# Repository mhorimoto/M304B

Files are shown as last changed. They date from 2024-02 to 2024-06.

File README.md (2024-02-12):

# M304B
UECS Controller Shield for Arduino MEGA I/F
Baby size

外観上の特徴としては、基板サイズが約半分となる。

## 1. PARTS

### 1-1. NIC

DIPタイプのW5500チップを使用したNICを使用する．

Tzt smart electronics USR-ES
https://ja.aliexpress.com/item/4000226162371.html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

### 1-2. LCD

20x4 Parallel connection (秋月コード P-10844)

## 2. Pin Assign

### 2-1. LCD (J1)

| I/O PIN | NAME | LCD PIN |
|:---:|---|:---:|
| | GND  | 1 |
| | Vdd  | 2 |
| | Vo | 3 |
| 37 | RS | 4 |
| 38 | R/W  | 5 |
| 39 | ENA  | 6 |
| 40 | DB0  | 7 |
| 41 | DB1  | 8 |
| 42 | DB2  | 9 |
| 43 | DB3  | 10 |
| 44 | DB4  | 11 |
| 45 | DB5  | 12 |
| 46 | DB6  | 13 |
| 47 | DB7  | 14 |
| | BL+  | 15 |
| | BL-  | 16 |

データピン８ピンすべて接続してある．

### 2-2. Relay OUT (J2)
リレー制御用のポートである．アクティブロー(負論理)である．

| J2 PIN | NAME |I/O PIN |
|:---:|---|:---:|
| 1 | RLY1 | 22 |
| 2 | RLY2 | 23 |
| 3 | RLY3 | 24 |
| 4 | RLY4 | 25 |
| 5 | RLY5 | 26 |
| 6 | RLY6 | 27 |
| 7 | RLY7 | 28 |
| 8 | RLY8 | 29 |
| 9 | Vdd  | +5V  |

リレー制御の自動・手動状態検知のための端子(STAT)はI/O PIN=31である.

|状態|D31の状態|
|:--:|:---:|
|自動| H |
|手動| L |

### 2-3. iM920 Interface (J3)
=== 排除する ===
iM920用のインタフェースで3.3V駆動です.

| J3 PIN | NAME  | I/O PIN |
|:---:|---|:---:|
| 1 | RESET | D6 |
| 2 | BUSY  | D2 |
| 3 | GND | GND |
| 4 | Vcc | 3.3V  |
| 5 | TX | D19(Rx) |
| 6 | RX | D18(Tx) |
| 7 | STATUS| D5 |

### 2-4. GNSS(GPS) Interface (J4)
=== 排除する ===
秋月電子通商のGNSSキット用．

| J4 PIN | NAME  | I/O PIN  |
|:---:|---|:---:|
| 1 | 1PPS  | D4 |
| 2 | RX | D14(Tx3) |
| 3 | TX | D15(Rx3) |
| 4 | GND | GND |
| 5 | Vcc | +5V |

### 2-5. Arrow Switch

アクティブローである．

| I/O PIN | 表示|回路図記号|
|:---:|:---:|:----:|
| 32 | 決定 (SW_ENTER)| SW6 |
| 33 |  ↑ (SW_A) | SW2 |
| 34 |  ↓ (SW_B) | SW3 |
| 35 |  ← (SW_C) | SW4 |
| 36 |  → (SW_D) | SW5 |

### 2-6. 選択
=== ADCを排除し ===
=== ロータリーエンコーダを使う。===
ADCに接続している．ロータリーエンコーダの代わりにADCの出力を得て選択する．

| I/O PIN | 表示 | 回路図記号 |
|:----:|:---:|:---:|
|  A15 | 選択(SELECTOR) | RV2 |

### 2-7. RESET
リセットボタンはArduino MEGAのRESETピンへ直結していると同時にNICのRESETピンにも接続されている．アクティブローである．

### 2-8. SAFEMODE Switch
UECSの初期設定を行う際に必要となるスイッチ．UARDECS_Libraryの既定値である

| I/O PIN | 表示 | 回路図記号 |
|:----:|:---:|:---:|
|  D3  | 初期設定(SAFEMODE) | SW7 |

### 2-9. JA pins (Analog ports)
以下のピン配置で3.3V用8ポート，5V用7ポートがある．
ソフトウェアで入出力の両用に使える．

| XH PIN | 意味 |
|:---:|:---|
| 1 | GND |
| 2 | CPUのAnalog port  |
| 3 | 電源 (3.3V or 5V)  |

コネクタとADCポートの関係

JA2〜JA7削除
JA10〜JA14削除

| PORT名 | 電圧 | I/O PIN |
|:-----:|:----:|:---:|
|  JA0  | 3.3V | A0 |
|  JA1  | 3.3V | A1 |
|  JA2  | 3.3V | A2 |
|  JA3  | 3.3V | A3 |
|  JA4  | 3.3V | A4 |
|  JA5  | 3.3V | A5 |
|  JA6  | 3.3V | A6 |
|  JA7  | 3.3V | A7 |
|  JA8  |  5V  | A8 |
|  JA9  |  5V  | A9 |
|  JA10 |  5V  | A10 |
|  JA11 |  5V  | A11 |
|  JA12 |  5V  | A12 |
|  JA13 |  5V  | A13 |
|  JA14 |  5V  | A14 |

### 2-10. JD pins (Digital ports)
以下のピン配置で7ポートある．ソフトウェアで入出力を切り替えられる．

| XH PIN | 意味 |
|:---:|:---|
| 1 | GND |
| 2 | CPUのDigital port  |

コネクタとDIOポートの関係
JD10〜JD13削除

| PORT名 | I/O PIN |
|:-----:|:---:|
|  JD7  | D7 |
|  JD8  | D8 |
|  JD9  | D9 |
|  JD10 | D10 |
|  JD11 | D11 |
|  JD12 | D12 |
|  JD13 | D13 |

### 2-11. UART (JX2)
外部の装置とUART接続するためのポートが準備されている．
ポート名はJX2．電圧レベルは5V．接続先の送受関係は，2ピンに対象体のRxを3ピンにTxを接続する．

| XH PIN番号 | I/O PIN |
|:---:|:---:|
| 1 | GND |
| 2 | D16 (Tx2) |
| 3 | D17 (Rx2) |

### 2-12. TEST Pad
独自にテストを行う際の独立したDIO pinのパッド．

| Pad名 | I/O PIN |
|:-----:|:---:|
| JD30  | D30 |
| JD48  | D48 |
| JD49  | D49 |

### 2-13. I2C Devices

標準で搭載されているI2Cデバイスは以下の通り．

| Address | 名称 |
|:---:|:---|
| 0x50 | EEPROM AT24C256 |
| 0x68 | RTC DS1307 |

* EEPROM
AT24C256 を使用している．32kBytesの容量がある．
* RTC (Address=0x68)
DS1307を使用してる．(DS1307RTC)

https://stackedit.io/app#

## 3.Software

### 3-1. AT24C256 EEPROM

データの保存を行う他に重要な役割がある．

UECS-IDとMACアドレスを以下のアドレスに記録する．MSB first，Big endianにて記録する．

|  Address | Data |
|:---:|:---|
| 00H〜05H | UECS-ID |
| 06H〜0BH | MAC Address |
| 0CH〜1FH | Reserved |
| 20H〜7FFFH | Data |

* UECS-ID: 10100C00000B
* MAC Address: 02:A2:73:0B:xx:xx

### 3-2. M304_Library

M304_Libraryは，M304を使用する際に初期化やポート名を決定してくれるヘッダファイルと若干の関数がまとめられたファイル．
現状では，Arduino-IDE(arduino-cli)が使用できるディレクトリにコピーして使う．
将来的には，このディレクトリから分離されて，Arduino-IDEなどのライブラリ管理から管理できるようにする．
同時にUARDECS_MEGAとの整合も図る．

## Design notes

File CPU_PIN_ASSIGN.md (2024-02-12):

# M304 Arduino CPU Pin Assign

## 1. Pin Assign 

| I/O PIN | NAME | LCD PIN |
|:---:|---|:---:|
| | GND  | 1 |
| | Vdd  | 2 |
| | Vo | 3 |
| 37 | RS | 4 |
| 38 | R/W  | 5 |
| 39 | ENA  | 6 |
| 40 | DB0  | 7 |
| 41 | DB1  | 8 |
| 42 | DB2  | 9 |
| 43 | DB3  | 10 |
| 44 | DB4  | 11 |
| 45 | DB5  | 12 |
| 46 | DB6  | 13 |
| 47 | DB7  | 14 |
| | BL+  | 15 |
| | BL-  | 16 |

データピン８ピンすべて接続してある．

### 2-2. Relay OUT (J2)
リレー制御用のポートである．アクティブロー(負論理)である．

| J2 PIN | NAME |I/O PIN |
|:---:|---|:---:|
| 1 | RLY1 | 22 |
| 2 | RLY2 | 23 |
| 3 | RLY3 | 24 |
| 4 | RLY4 | 25 |
| 5 | RLY5 | 26 |
| 6 | RLY6 | 27 |
| 7 | RLY7 | 28 |
| 8 | RLY8 | 29 |
| 9 | Vdd  | +5V  |

リレー制御の自動・手動状態検知のための端子(STAT)はI/O PIN=31である.

|状態|D31の状態|
|:--:|:---:|
|自動| H |
|手動| L |

### 2-3. iM920 Interface (J3)
iM920用のインタフェースで3.3V駆動です.

| J3 PIN | NAME  | I/O PIN |
|:---:|---|:---:|
| 1 | RESET | D6 |
| 2 | BUSY  | D2 |
| 3 | GND | GND |
| 4 | Vcc | 3.3V  |
| 5 | TX | D19(Rx) |
| 6 | RX | D18(Tx) |
| 7 | STATUS| D5 |

### 2-4. GNSS(GPS) Interface (J4)
秋月電子通商のGNSSキット用．

| J4 PIN | NAME  | I/O PIN  |
|:---:|---|:---:|
| 1 | 1PPS  | D4 |
| 2 | RX | D14(Tx3) |
| 3 | TX | D15(Rx3) |
| 4 | GND | GND |
| 5 | Vcc | +5V |

### 2-5. Arrow Switch

アクティブローである．

| I/O PIN | 表示|回路図記号|
|:---:|:---:|:----:|
| 32 | 決定 (SW_ENTER)| SW6 |
| 33 |  ↑ (SW_A) | SW2 |
| 34 |  ↓ (SW_B) | SW3 |
| 35 |  ← (SW_C) | SW4 |
| 36 |  → (SW_D) | SW5 |

### 2-6. 選択
ADCに接続している．ロータリーエンコーダの代わりにADCの出力を得て選択する．

| I/O PIN | 表示 | 回路図記号 |
|:----:|:---:|:---:|
|  A15 | 選択(SELECTOR) | RV2 |

### 2-7. RESET
リセットボタンはArduino MEGAのRESETピンへ直結していると同時にNICのRESETピンにも接続されている．アクティブローである．

### 2-8. SAFEMODE Switch
UECSの初期設定を行う際に必要となるスイッチ．UARDECS_Libraryの既定値である

| I/O PIN | 表示 | 回路図記号 |
|:----:|:---:|:---:|
|  D3  | 初期設定(SAFEMODE) | SW7 |

### 2-9. JA pins (Analog ports)
以下のピン配置で3.3V用8ポート，5V用7ポートがある．
ソフトウェアで入出力の両用に使える．

| XH PIN | 意味 |
|:---:|:---|
| 1 | GND |
| 2 | CPUのAnalog port  |
| 3 | 電源 (3.3V or 5V)  |

コネクタとADCポートの関係

| PORT名 | 電圧 | I/O PIN |
|:-----:|:----:|:---:|
|  JA0  | 3.3V | A0 |
|  JA1  | 3.3V | A1 |
|  JA2  | 3.3V | A2 |
|  JA3  | 3.3V | A3 |
|  JA4  | 3.3V | A4 |
|  JA5  | 3.3V | A5 |
|  JA6  | 3.3V | A6 |
|  JA7  | 3.3V | A7 |
|  JA8  |  5V  | A8 |
|  JA9  |  5V  | A9 |
|  JA10 |  5V  | A10 |
|  JA11 |  5V  | A11 |
|  JA12 |  5V  | A12 |
|  JA13 |  5V  | A13 |
|  JA14 |  5V  | A14 |

### 2-10. JD pins (Digital ports)
以下のピン配置で7ポートある．ソフトウェアで入出力を切り替えられる．

| XH PIN | 意味 |
|:---:|:---|
| 1 | GND |
| 2 | CPUのDigital port  |

コネクタとDIOポートの関係

| PORT名 | I/O PIN |
|:-----:|:---:|
|  JD7  | D7 |
|  JD8  | D8 |
|  JD9  | D9 |
|  JD10 | D10 |
|  JD11 | D11 |
|  JD12 | D12 |
|  JD13 | D13 |

### 2-11. UART (JX2)
外部の装置とUART接続するためのポートが準備されている．
ポート名はJX2．電圧レベルは5V．接続先の送受関係は，2ピンに対象体のRxを3ピンにTxを接続する．

| XH PIN番号 | I/O PIN |
|:---:|:---:|
| 1 | GND |
| 2 | D16 (Tx2) |
| 3 | D17 (Rx2) |

### 2-12. TEST Pad
独自にテストを行う際の独立したDIO pinのパッド．

| Pad名 | I/O PIN |
|:-----:|:---:|
| JD30  | D30 |
| JD48  | D48 |
| JD49  | D49 |

https://stackedit.io/app#

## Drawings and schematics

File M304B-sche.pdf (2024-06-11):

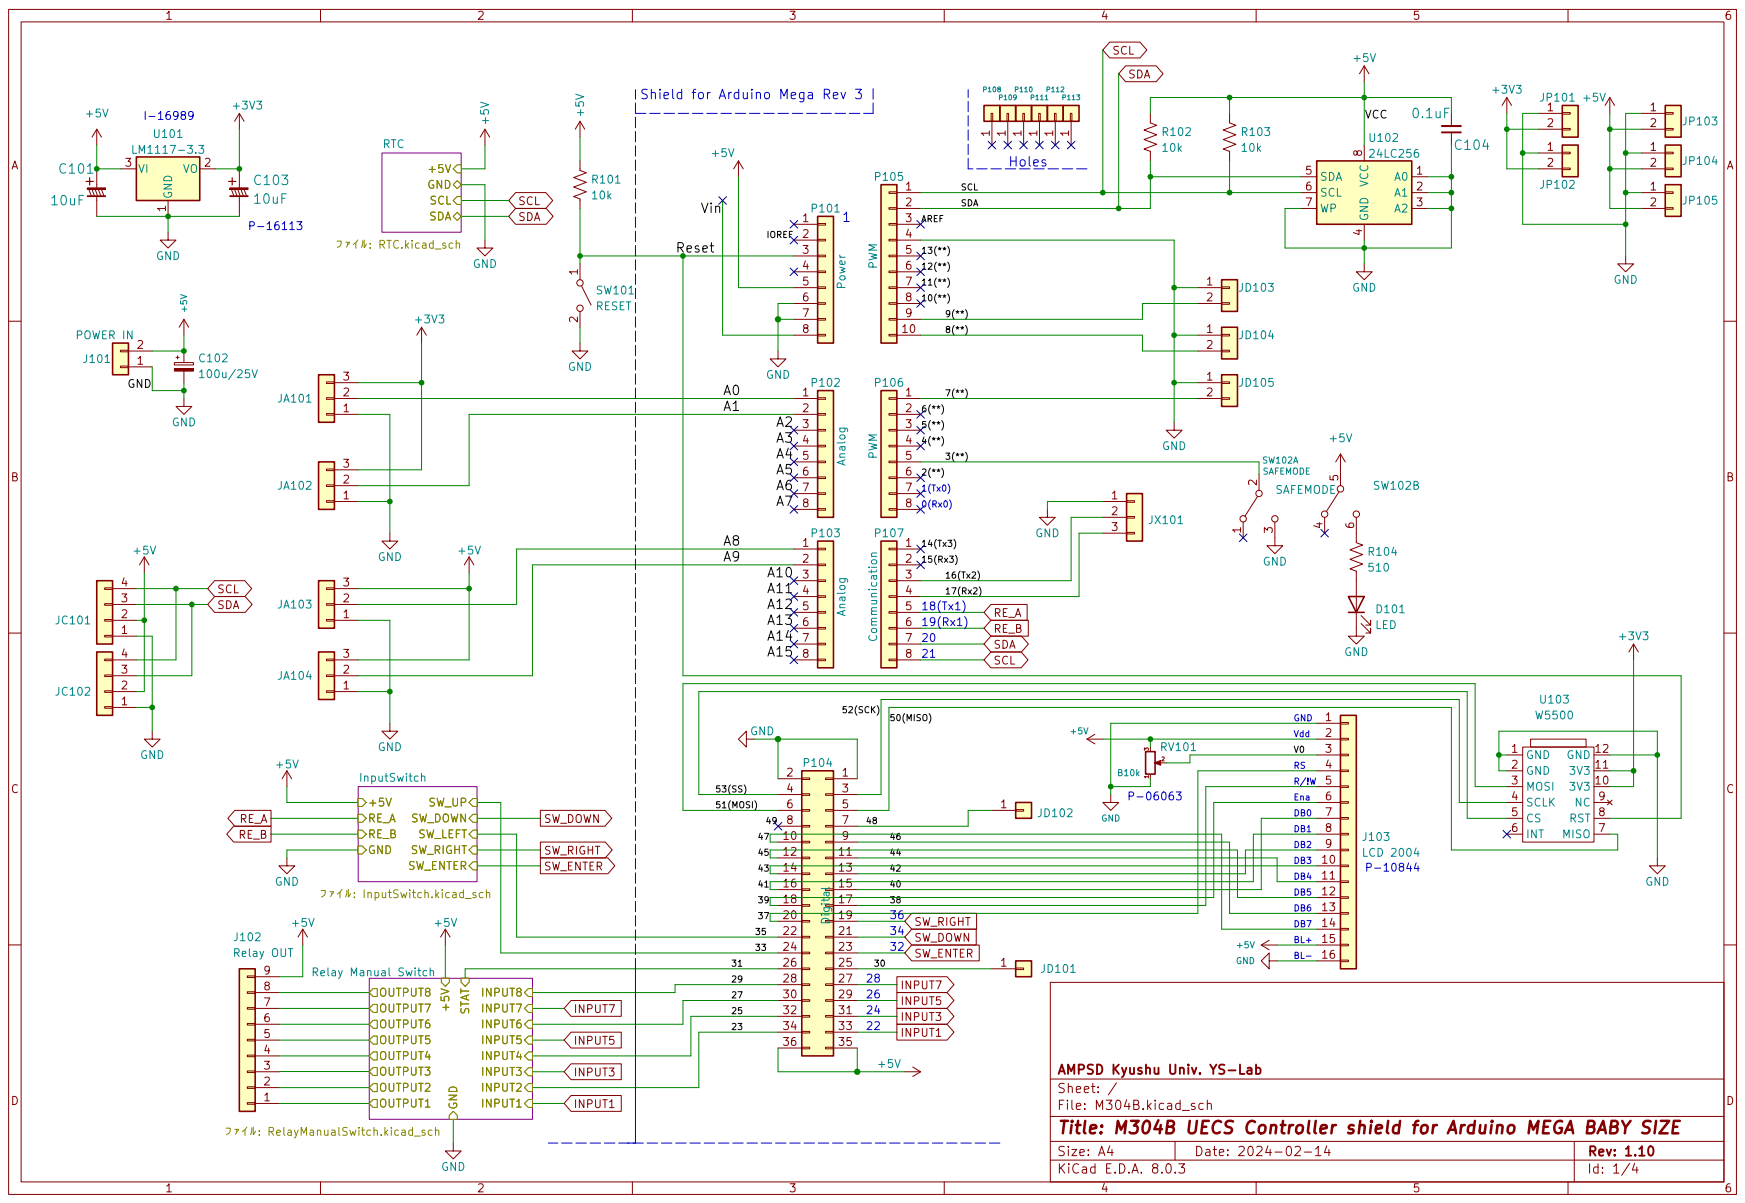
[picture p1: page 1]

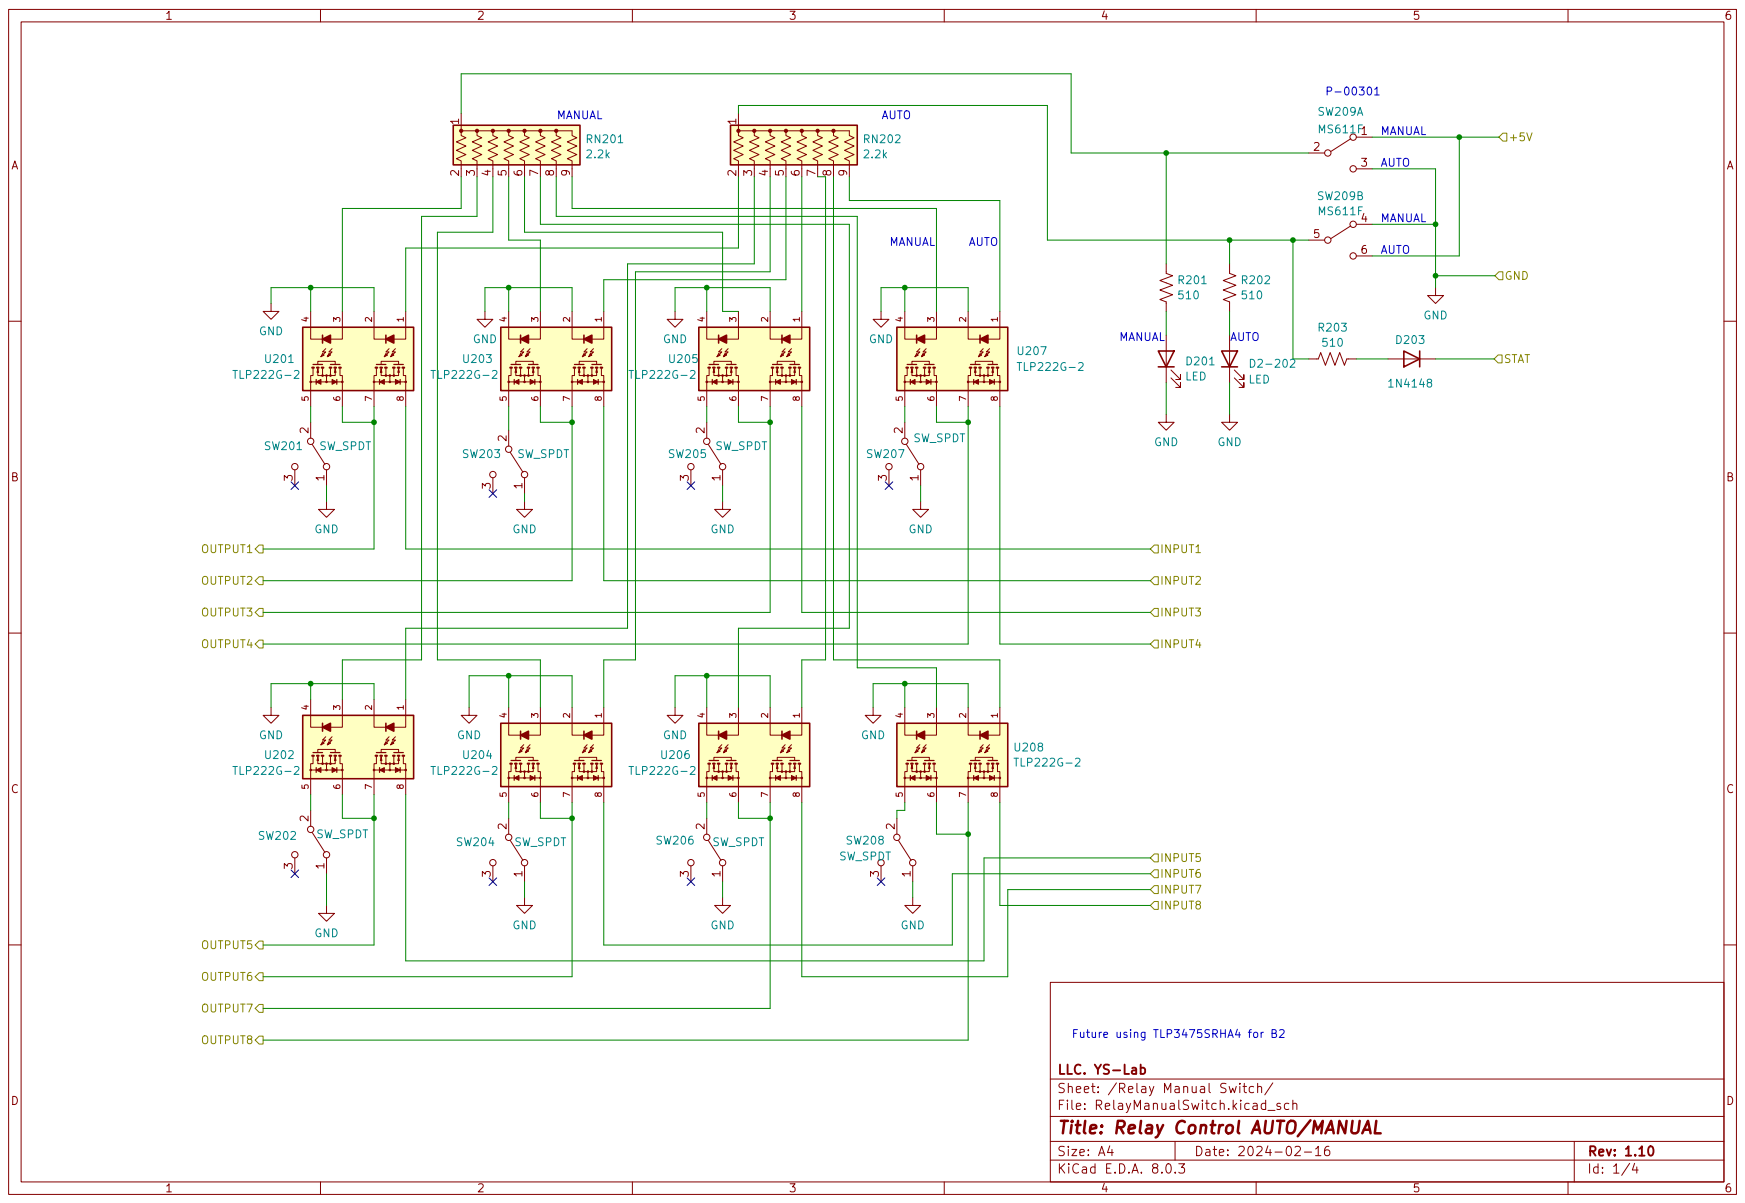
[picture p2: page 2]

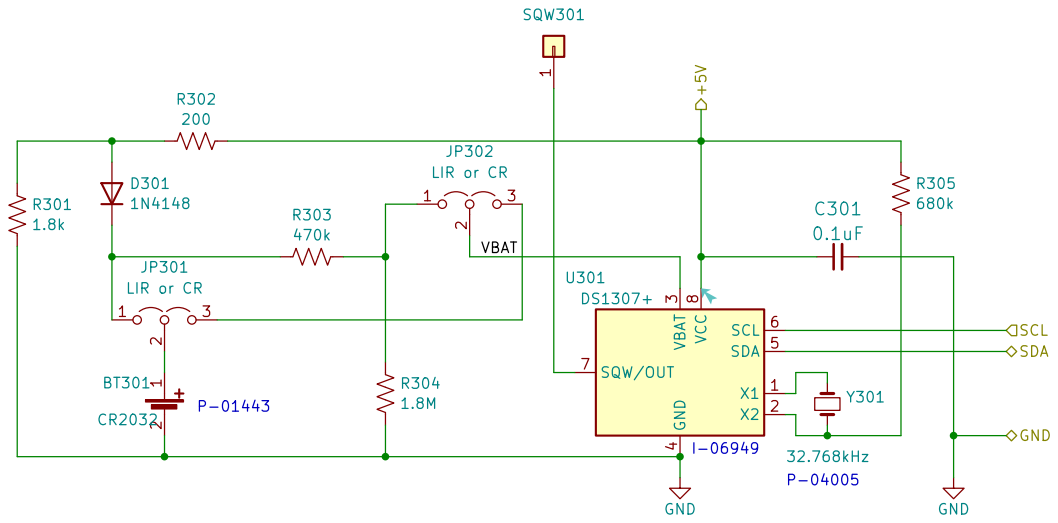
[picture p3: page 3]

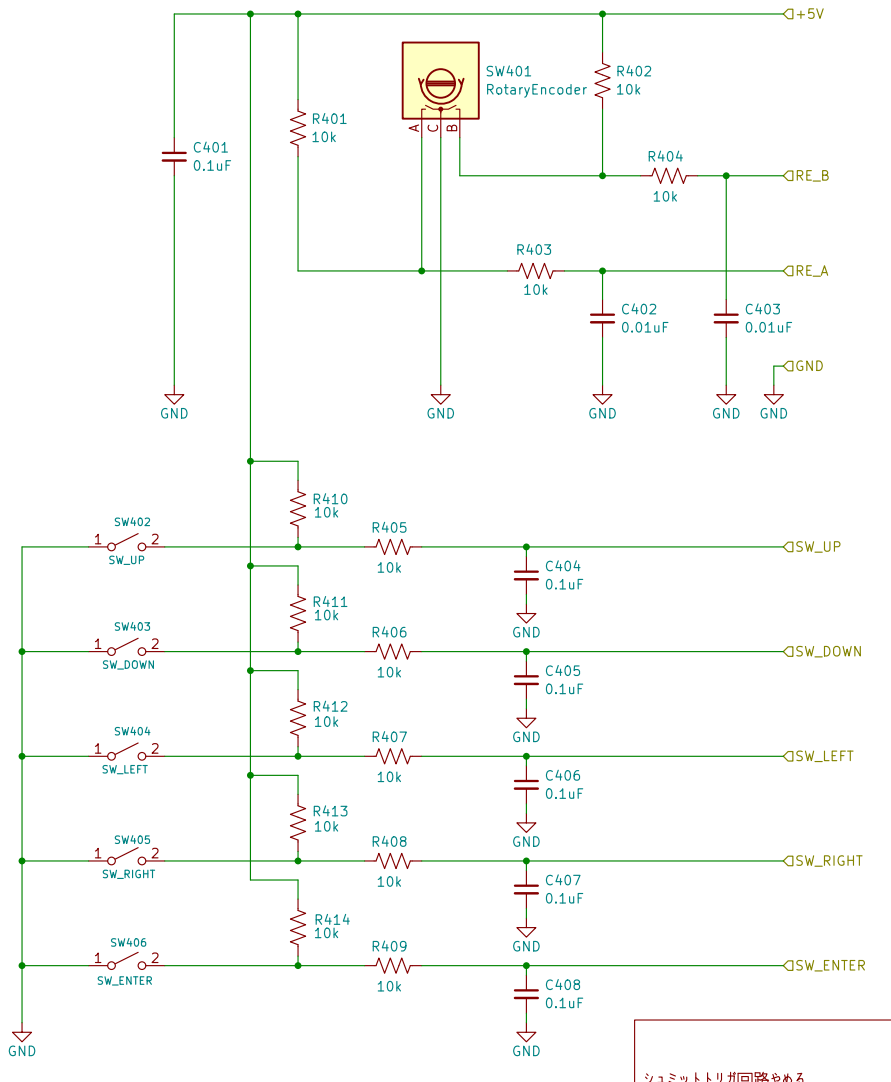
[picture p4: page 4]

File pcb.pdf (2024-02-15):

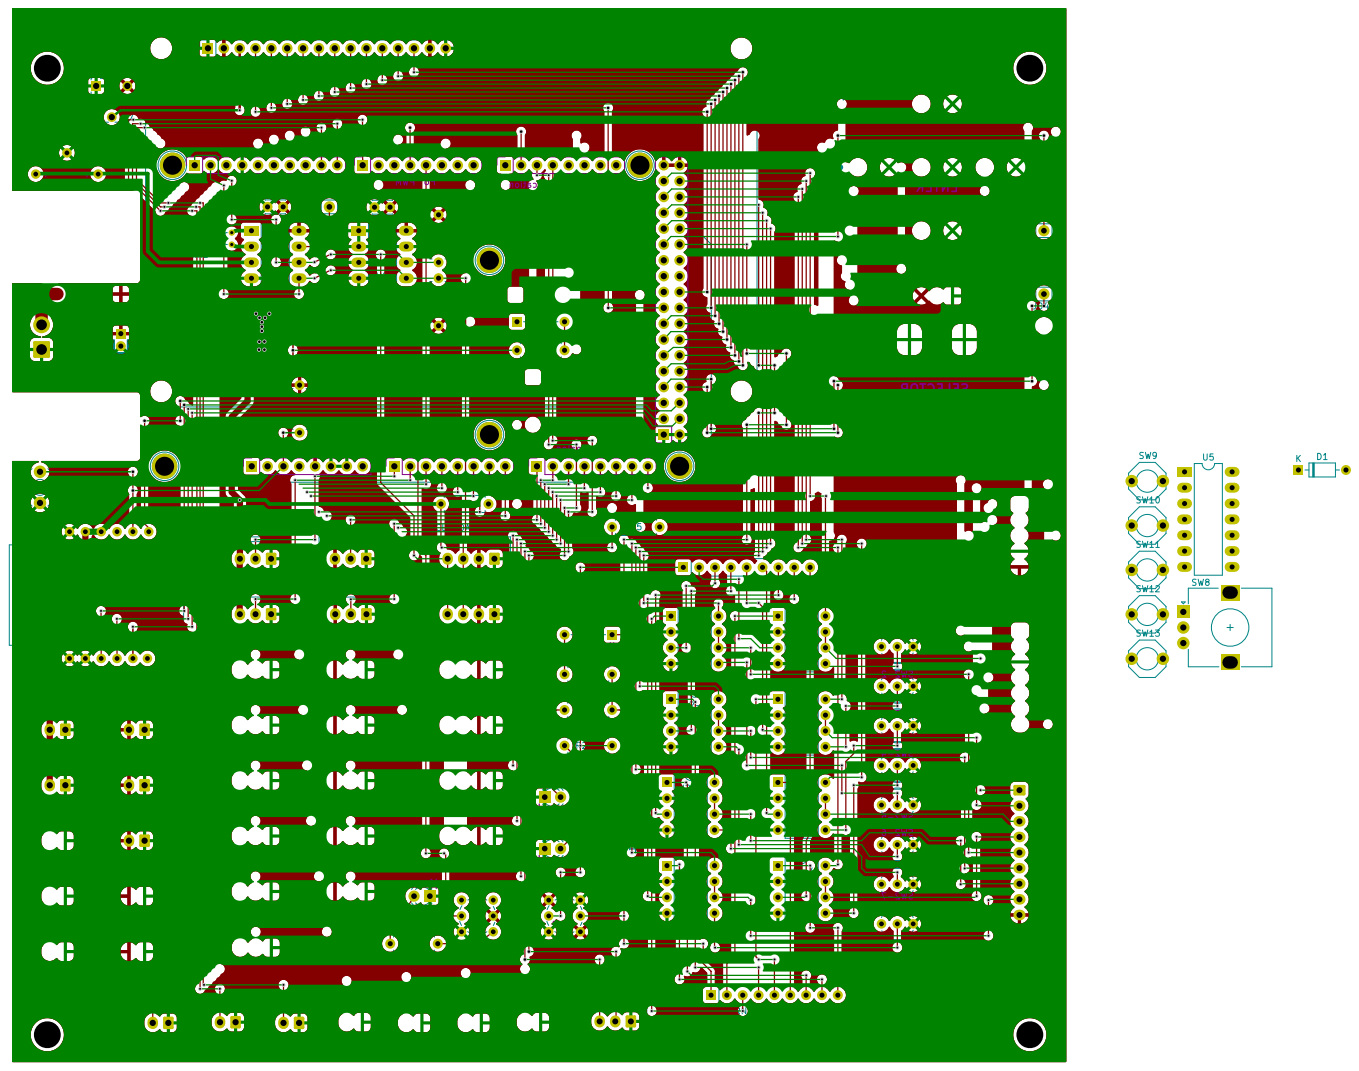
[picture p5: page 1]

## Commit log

2024-02-14 もう少し
    [InputSwitch.kicad_sch, M304B.kicad_sch, RTC.kicad_sch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]
2024-02-15 細かい整形
    [InputSwitch.kicad_sch, M304B.kicad_sch, RTC.kicad_sch]
2024-02-15 InputSwitchのスイッチ名称の変更が必要
    [InputSwitch.kicad_sch, RTC.kicad_sch, RelayManualSwitch.kicad_sch]
2024-02-19 PCB配置作業中
    [InputSwitch.kicad_sch, M304B.kicad_sch, RTC.kicad_sch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]
